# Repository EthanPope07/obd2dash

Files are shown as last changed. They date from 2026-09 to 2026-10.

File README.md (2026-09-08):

# OBD2Dash

An ESP32-S3 CAN-to-BLE bridge for an iPad vehicle dashboard. The firmware discovers each ECU's supported current-data PIDs and forwards complete raw responses through a versioned BLE GATT stream.

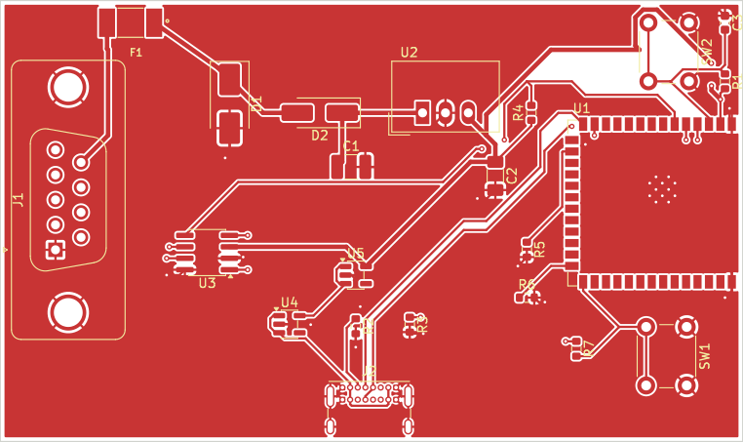
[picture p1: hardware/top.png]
Compact board preview


## Status

The original reader was a breadboard diagnostic sketch. This revision replaces its receive path and adds supported-PID discovery, ISO-TP reassembly and BLE. The new firmware has host regression tests; vehicle and iPad integration testing are still required. Do not represent the new implementation as vehicle-validated yet.

The PCB is a compact prototype, not a fabrication-qualified automotive module. See hardware/Review.md for the supplied review and its unresolved decoupling, component-selection and power-protection findings. That report is preserved as source evidence, not a new electrical signoff.

## Scope of "all PIDs"

- Service 01 (current powertrain data), PID 00 through FF.
- Every advertised support page, not a fixed shortlist of dashboard sensors.
- Separate support maps and responses for eight physical ECU addresses.
- Classical CAN with 11-bit IDs: requests 7E0–7E7, responses 7E8–7EF.
- 500 kbit/s by default; configurable 250 kbit/s.
- Raw response preservation, including multi-frame PIDs. The dashboard applies PID-specific formulas.
- Not manufacturer-specific services, all OBD diagnostic modes, 29-bit CAN, CAN FD, or legacy K-line/J1850.

A vehicle cannot return a PID it does not implement. A discovery timeout is reported as incomplete, not silently interpreted as no support.

## Data flow

CAN request -> ECU response -> ISO-TP reassembly -> timestamped raw PID record -> 20-byte BLE fragments -> iPad reassembly and decoding.

There is one outstanding physical request at a time. All supported data PIDs are polled round-robin; support pages are refreshed between sweeps after at least 60 seconds. Requests have a 50 ms minimum gap, 300 ms inactivity timeout and 5-second absolute deadline. Discovery retries transient failures up to three times. Sample failures produce status records and are retried on later sweeps.

This prioritizes coverage rather than high-rate gauges: polling many PIDs or offline ECUs makes a sweep longer. No fixed update-rate guarantee is claimed.

## Hardware and build

The supplied PCB identifies ESP32-S3-WROOM-1 and TI TCAN337:
- GPIO4 -> TCAN337 TXD
- GPIO5 <- TCAN337 RXD

Confirm the external connector cable pinout and power design before connecting hardware. The firmware sends only Mode 01 requests and ISO-TP flow control; BLE provides no arbitrary CAN-write interface.

Open firmware/obd2dash/obd2dash.ino in Arduino IDE. Select ESP32S3 Dev Module using the Espressif ESP32 package. BLE and TWAI ship with that package. Configure pins and bitrate in Config.h. No WiFi credentials or cloud services are required.

    arduino-cli compile --fqbn esp32:esp32:esp32s3 firmware/obd2dash

## Repository

- firmware/obd2dash: request engine, protocol core and BLE stream
- docs/BLE.md: exact wire format and app integration
- tools/decode_ble.py: reference decoder for notification hex lines
- tests: host protocol and decoder regression tests
- hardware: supplied KiCad source, local footprints, DRC reports and previews

## Tests

    g++ -std=c++17 -Wall -Wextra -Werror tests/protocol_test.cpp -o protocol_test
    ./protocol_test
    python -m unittest discover -s tests -p "test_*.py"

The C++ tests exercise support-map boundaries, independent ECU maps, all 4,088 ISO-TP multi-frame lengths from 8 to 4,095 bytes, sequence rollover/errors, negative responses and maximum-length BLE serialization. Tests do not replace CAN simulator, vehicle or radio testing.

## References

- [Espressif BLE notification example](https://github.com/espressif/arduino-esp32/tree/master/libraries/BLE/examples/Notify)
- [ISO-TP transport overview](https://docs.kernel.org/networking/iso15765-2.html)
- [OBD support-page explanation](https://www.csselectronics.com/pages/obd2-explained-simple-intro)

## Verified build

Compiled successfully with Espressif Arduino-ESP32 3.3.11 (bundled BLE 3.3.11), target esp32:esp32:esp32s3, board defaults.

- Program storage: 576,620 / 1,310,720 bytes (43%).
- Static global RAM: 31,744 / 327,680 bytes (9%).
- Host C++ protocol regression suite: passed.
- Python BLE decoder suite: 4 tests passed.

No device was flashed. These compile figures do not measure peak runtime RAM. Vehicle/CAN simulator tests and iPad integration remain outstanding; follow docs/VALIDATION.md.

## iPad dashboard

The native SwiftUI receiving app is in [ipad](ipad/README.md). Open ipad/OBD2Dash.xcodeproj on a Mac, select your signing team and run on an iPad with iPadOS 17+. It automatically connects while foregrounded and displays RPM, speed and coolant gauges alongside a searchable list of supported/observed PIDs.

Unknown PIDs are shown as raw bytes, not guessed numbers. The app has an explicitly labeled --demo mode for UI previews. See the app README for build and physical-device validation instructions.

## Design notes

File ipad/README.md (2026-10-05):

# OBD2Dash for iPad

A native SwiftUI dashboard for the BLE stream in this repository. Requires iPadOS 17 or newer. No third-party app dependencies.

## Build with GitHub and install from Windows (free Apple account)

1. Open [the iPad app workflow](https://github.com/EthanPope07/obd2dash/actions/workflows/ipad.yml). Builds run automatically when app code changes. To rebuild manually, sign in as a repository collaborator, choose **Run workflow**, and select `main`.
2. Open a successful run. Under **Artifacts**, download **OBD2Dash-iPad-unsigned** (GitHub sign-in required), then extract the downloaded ZIP to get `OBD2Dash-unsigned.ipa`. Artifacts expire after 30 days; run the workflow again if needed.
3. Install [Sideloadly for Windows](https://sideloadly.io/) and its required Apple device components using its current official instructions. Connect your iPad by USB, unlock it, and trust the computer.
4. Select the iPad and drag the `.ipa` into Sideloadly. Use **Apple ID Sideload** with your own free Apple account and start installation. Enter account credentials only in the local signing tool, never in this repository or GitHub Actions.
5. If prompted, trust your developer profile under **Settings > General > VPN & Device Management**. Enable **Settings > Privacy & Security > Developer Mode** and restart if requested.
6. Open OBD2Dash and allow Bluetooth access. Power on the scanner with this repository's firmware; the foreground app connects automatically.

Free-account signing lasts seven days. Refresh or reinstall with Sideloadly using the same account and bundle identifier; see its [FAQ](https://sideloadly.io/faq) for automatic refresh and account limits. No paid developer membership or personally owned Mac is needed for this workflow. The iPad must run iPadOS 17 or newer.

GitHub tests the protocol core, builds the simulator app, and builds an unsigned Release app for physical ARM64 iPads. It checks the device platform and architecture, packages `Payload/OBD2Dash.app` as an IPA, and supplies `SHA256SUMS.txt`. The IPA cannot be installed directly until Sideloadly signs it. No Apple credentials or signing certificates are used by CI. A successful build does not verify physical installation or BLE behavior; those still require an iPad and scanner.

## Run on an iPad with Xcode

1. Clone the repository on a Mac with Xcode 15 or newer (Xcode 16 recommended).
2. Open ipad/OBD2Dash.xcodeproj.
3. In the OBD2Dash target's Signing & Capabilities, select your development team. Change the bundle identifier if your account requires it.
4. Select your attached iPad as the run destination and run the app. Enable Developer Mode on the iPad if requested.
5. Allow Bluetooth access when prompted, then power on the scanner running this repository's firmware.

The app scans for the service UUID, connects, discovers the notify characteristic and subscribes automatically. It remembers the first successfully subscribed scanner. Use the connection menu to reconnect or forget that scanner. It will not silently switch to a different remembered device.

Automatic connection/reconnection is foreground-only. Backgrounding the app stops scanning and disconnects; returning to the foreground reconnects. Bluetooth permission and a powered-on radio are required. It does not pair through the iPad Settings screen.

## Dashboard

- Three large gauges: RPM, speed in km/h, and coolant temperature in Celsius.
- A gauge ECU selector keeps values from different ECUs separate.
- A searchable list includes every PID advertised in support maps or observed in samples, keyed by ECU and PID.
- Common scalar PIDs show numeric values and units. Unknown/encoded PIDs remain visible as raw data; expand any row to inspect the bytes and device timestamp.
- Support-map rows start as awaiting a first sample. Timeouts and ECU errors never become zero-valued readings.
- Gauges blank when disconnected or when the latest successful sample is over 15 seconds old. Old list values remain marked stale.
- The app may wait until the next support sweep to learn all supported PIDs. It never invents unsupported rows.

The firmware polls broadly, so vehicles with many PIDs may not refresh gauges quickly. A priority polling mode can be added to the firmware later; it is not implied by this UI.

## Preview without a scanner

Open the top-right three-dot menu and choose **Demo: 2017 Infiniti QX70**. No scanner or Bluetooth permission is needed to run the simulation. The gauges and 19 PID rows update once per second through a repeating stop-and-go drive, with acceleration, cruise, braking, idle and gradual engine warm-up.

An orange demo banner and connection status identify all readings as simulated. This is an illustrative vehicle profile, not measured QX70 data or a claim that your car supports every demonstrated PID. Values pass through the same PID decoder used for live readings.

Demo pauses Bluetooth scanning and disconnects any scanner without forgetting it. **Exit demo mode** clears simulated records and resumes normal Bluetooth connection behavior. Simulation pauses in the background. Xcode's `--demo` launch argument still works for previews.

## Protocol and testing

The app shares a Foundation-only parser/model source with the OBDCore Swift package. It matches docs/BLE.md, checks packet bounds and identity, discards gaps and incomplete records, and expires partial reassembly after 15 seconds. Device milliseconds are uptime, not calendar time.

Run on macOS:

    swift test --package-path ipad/OBDCore
    xcodebuild -project ipad/OBD2Dash.xcodeproj -scheme OBD2Dash -sdk iphonesimulator -destination 'generic/platform=iOS Simulator' CODE_SIGNING_ALLOWED=NO build

The GitHub workflow runs these checks on macOS. The development host used to add this app was Windows, so native iPad UI rendering and physical CoreBluetooth behavior must still be verified on an iPad.

Numeric decoding is intentionally limited to implemented scalar definitions with exact expected byte counts. Other PIDs preserve their complete raw readings. Decoder reference: https://www.csselectronics.com/pages/obd2-pid-table-on-board-diagnostics-j1979

## Files

- OBD2Dash/DashboardModel.swift: foreground connection lifecycle and notification handling
- OBD2Dash/DashboardView.swift: gauges and searchable PID list
- OBDCore/Sources/OBDCore/Telemetry.swift: reassembly, support maps, scalar decoding and freshness
- OBDCore/Tests: regression tests

No firmware modifications are needed. No vehicle-write control is exposed by the app.

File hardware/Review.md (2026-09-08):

# obd2Dash compact prototype revision

The board outline has been reduced from **95 × 54.5 mm to 82.5 × 49 mm**, a **21.9% reduction in PCB area** (5,177.5 to 4,042.5 mm²). This is the PCB outline, not the assembled envelope: the USB connector and ESP32 antenna extend beyond it.

Open `obd2Dash.kicad_pro` in KiCad 10 with the other files in this folder. The original OneDrive project was not modified. The schematic, component values, net assignments, and two-layer construction are preserved.

## What changed

- Moved the DE-9 connector J1 10 mm inward and moved fuse F1 5 mm upward; reduced unused space at the left and top edges.
- Rerouted the J1 power feed and CANH/CANL connections to accommodate the connector move.
- Replaced the long IO4/IO5 routes around the lower and right edges with shorter routes on the back layer. This removes the copper-at-the-board-edge defects.
- Connected the previously isolated C3 ground, R7 3.3 V supply, and J2 CC2 connection to R3.
- Adjusted the ESP32 enable trace near SW2 to restore clearance.
- Added a front ground pour, retained the back ground pour, and refilled both. The ESP32 footprint's antenna keepout remains present, prohibiting tracks, vias, and zone fill.
- Corrected USB ground thermal connections and SW2 ground thermal clearance.
- Increased the twelve 0.20 mm ESP32 ground-pad holes to 0.30 mm to meet the existing minimum-hole rule. This is a deliberate footprint customization; the associated copper pads are retained and pass annular-width checks.
- Corrected the undersized fuse reference text and moved board-edge-crossing connector/module graphics to the fabrication layer. Repositioned J1's reference inside the outline.

## Verification

Checked with KiCad CLI **10.0.4**, with copper zones refilled and schematic parity enabled.

| Check | Original | Revised |
|---|---:|---:|
| DRC errors, excluding separately reported missing connections | 51 | 0 |
| Missing connections | 3 | 0 |
| Schematic parity issues | 0 | 0 |
| DRC warnings | 28 | 1 |

The original 79 DRC violations comprised 29 clearance, 8 copper-edge clearance, 12 hole-size, 2 incomplete thermal relief, 2 dangling-via, 3 silkscreen-edge, 1 text-height, and 22 unavailable-library findings. The three missing connections were reported separately.

The remaining warning is **U1 footprint does not match the RF_Module library copy**. It is visible in `drc-final.json` and has not been excluded. Local footprint libraries are bundled as project snapshots to make the supplied project portable; they are not independent manufacturer verification of the footprints. Review the customized ESP32 footprint before updating it from any library, since a library update could overwrite its drill and graphics changes.

The project retains its existing rule severities and exclusions. It adds one narrowly scoped rule in `obd2Dash.kicad_dru`: **0.15 mm clearance between pads of J2 only**, matching the supplied USB4085 footprint's pad spacing. Other default net clearance remains 0.20 mm; minimum copper-to-board-edge clearance remains 0.50 mm. Confirm that the chosen fabricator supports 0.15 mm spacing. This rule acknowledges the connector geometry; it is not a rerouting repair or a blanket relaxation of clearances. See [GCT's USB4085 documentation](https://gct.co/connector/usb4085) when checking the exact connector variant and land pattern.

The original USB D+/D− routes were retained. Their total segment lengths are approximately 45.78 mm and 45.65 mm, respectively; these totals include connector branches and are not a full differential-path or signal-integrity measurement. No controlled-impedance stackup was supplied, so USB impedance has not been validated. DRC does not verify signal integrity, EMC, thermal performance, or power-supply stability.

Native top and bottom copper plots were exported and visually reviewed. The PNG shows the top copper and silkscreen; the SVG files preserve more detail. The bottom plot is viewed through the board from above, not mirrored for assembly.

## Electrical issues still present in the source design

These were identified during the layout review and are not solved by reconnecting the existing nets:

1. **AP2112 USB regulator U4 has no local input or output capacitor in the supplied schematic.** C1 is on the vehicle-side converter input; C2 is on the combined 3.3 V rail after U5; C3 is on ESP32 EN. Add suitable local capacitors at U4 VIN and VOUT as part of a schematic revision. The manufacturer's typical application uses 1 µF input and output capacitors. [AP2112 datasheet](https://www.diodes.com/datasheet/download/AP2112.pdf).
2. **TCAN337 U3 has no dedicated local supply bypass capacitor.** Its shared bulk capacitor C2 is some distance away. Add a local 100 nF ceramic bypass at U3 VCC/GND and review bulk decoupling. [TI TCAN337 datasheet](https://www.ti.com/lit/ds/symlink/tcan337.pdf).
3. **The vehicle-input protection parts are not fully specified.** D1 is labeled only `D_Zener`, D2 only `D_Schottky`, and F1's 0.75 A value differs from the current footprint's `1812L200_12DR` name. Verify actual part numbers, ratings, and land patterns before ordering. This review does not establish automotive transient immunity or validate simultaneous vehicle/USB power operation.

The antenna overhang and keepout were preserved, consistent with Espressif's preference for placing the module antenna outside the base board. The assembled enclosure and nearby metal still need consideration. [Espressif PCB layout guidance](https://docs.espressif.com/projects/esp-hardware-design-guidelines/en/latest/esp32s3/pcb-layout-design.html).

## Further size reduction

This revision keeps the current parts and most of the established placement. Additional reduction would require a broader rearrangement of the regulator, USB circuit, and switches. The through-hole DE-9 connector, two large pushbuttons, and ESP32 module are the major physical constraints. A smaller connector or smaller switches would permit a more substantial reduction but would change the parts list. The present revision is a compact, connected prototype layout for review, not a fabrication-qualified electrical design.

## Included files

- Native board, unchanged schematic, project settings, and connector-specific design rule.
- Project-local footprint libraries and `fp-lib-table`.
- Original and final machine-readable DRC reports.
- `top.svg`, `bottom.svg`, and `top.png` previews.

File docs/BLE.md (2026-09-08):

# BLE protocol v1

Advertised name: OBD2Dash. Discover by service UUID, not name alone.

| Attribute | UUID | Properties |
|---|---|---|
| Service | 973a0001-6f8a-4db7-a735-79d348be7341 | Primary |
| Stream | 973a0002-6f8a-4db7-a735-79d348be7341 | Notify |
| Info | 973a0003-6f8a-4db7-a735-79d348be7341 | Read |

Subscribe to Stream using CoreBluetooth setNotifyValue(true, for:). The firmware does not require a larger MTU: every notification is 20 bytes, fitting the default 23-byte ATT MTU. The only writable attribute is the notification subscription descriptor. There is no CAN-command characteristic.

## Packet

All multi-byte fields are unsigned little-endian. Serialization is explicit; no compiler-dependent packed C struct is transmitted.

| Offset | Bytes | Meaning |
|---|---:|---|
| 0 | 1 | Version in high nibble (1); kind in low nibble |
| 1 | 1 | Requested PID, or support-page base |
| 2 | 2 | ECU response CAN ID (7E8–7EF) |
| 4 | 2 | Sample sequence, wraps at 65536 |
| 6 | 2 | Offset into the logical payload |
| 8 | 2 | Total logical payload length |
| 10 | 1 | Status |
| 11 | 1 | Fragment payload bytes (1–8) |
| 12 | 8 | Fragment bytes; unused trailing bytes zero-filled |

Kinds: 1 = PID sample, 2 = discovery support-page result.
Statuses: 0 = valid; 1 = timeout; 2 = negative ECU reply; 3 = malformed response; 4 = transport failure; 5 = bus unavailable/recovering.

The logical payload begins with milliseconds since boot (uint32 LE), then:
- Valid PID: raw data bytes after the 41/PID response prefix.
- Valid support page: four bitmap bytes in original ECU order (big-endian bit map).
- Negative response: one NRC byte.
- Other failures: no additional bytes. Never reuse previous sensor bytes as a new successful reading.

For bitmap base B, the most significant bit represents B+1; the least significant bit represents B+32. Continuation PIDs 20,40,...,E0 are support pages, not gauge values.

Example: sequence 0, ECU 7E8, PID 0C, timestamp 0, raw 1A F8:
    11 0c e8 07 00 00 00 00 06 00 00 06 00 00 00 00 1a f8 00 00
RPM is (0x1AF8)/4 = 1726 RPM. Other PIDs can contain multiple values and flags; retain their raw bytes.

## Reassembly

Start at offset zero. Require the same version/kind, ECU, PID, sequence, total length and status for all fragments, and exactly contiguous offsets. Emit a sample only when all total bytes are received. Reject out-of-range lengths, gaps, duplicate or reordered fragments. Clear partial state on disconnect and expire incomplete records. Sequence numbers and timestamps reset on reboot and wrap; they are not wall-clock time.

Notifications are best effort. The 15 ms fragment pacing reduces congestion but does not acknowledge delivery. Use timestamps to mark readings stale. A sequence gap can also reflect samples produced before subscription. Discovery repeats periodically, so a client subscribing late may wait until the next support sweep for all bitmap pages.

A Python reference reassembler is in tools/decode_ble.py; feed one notification hex string per line. The new native iPad client in ipad/ implements this format. It is a new receiving app, not a claim of compatibility with any earlier unpublished app.

## Access

This prototype does not enable pairing or encryption. Nearby clients can subscribe to telemetry. Do not transmit identity/location data through this interface without designing appropriate access control.

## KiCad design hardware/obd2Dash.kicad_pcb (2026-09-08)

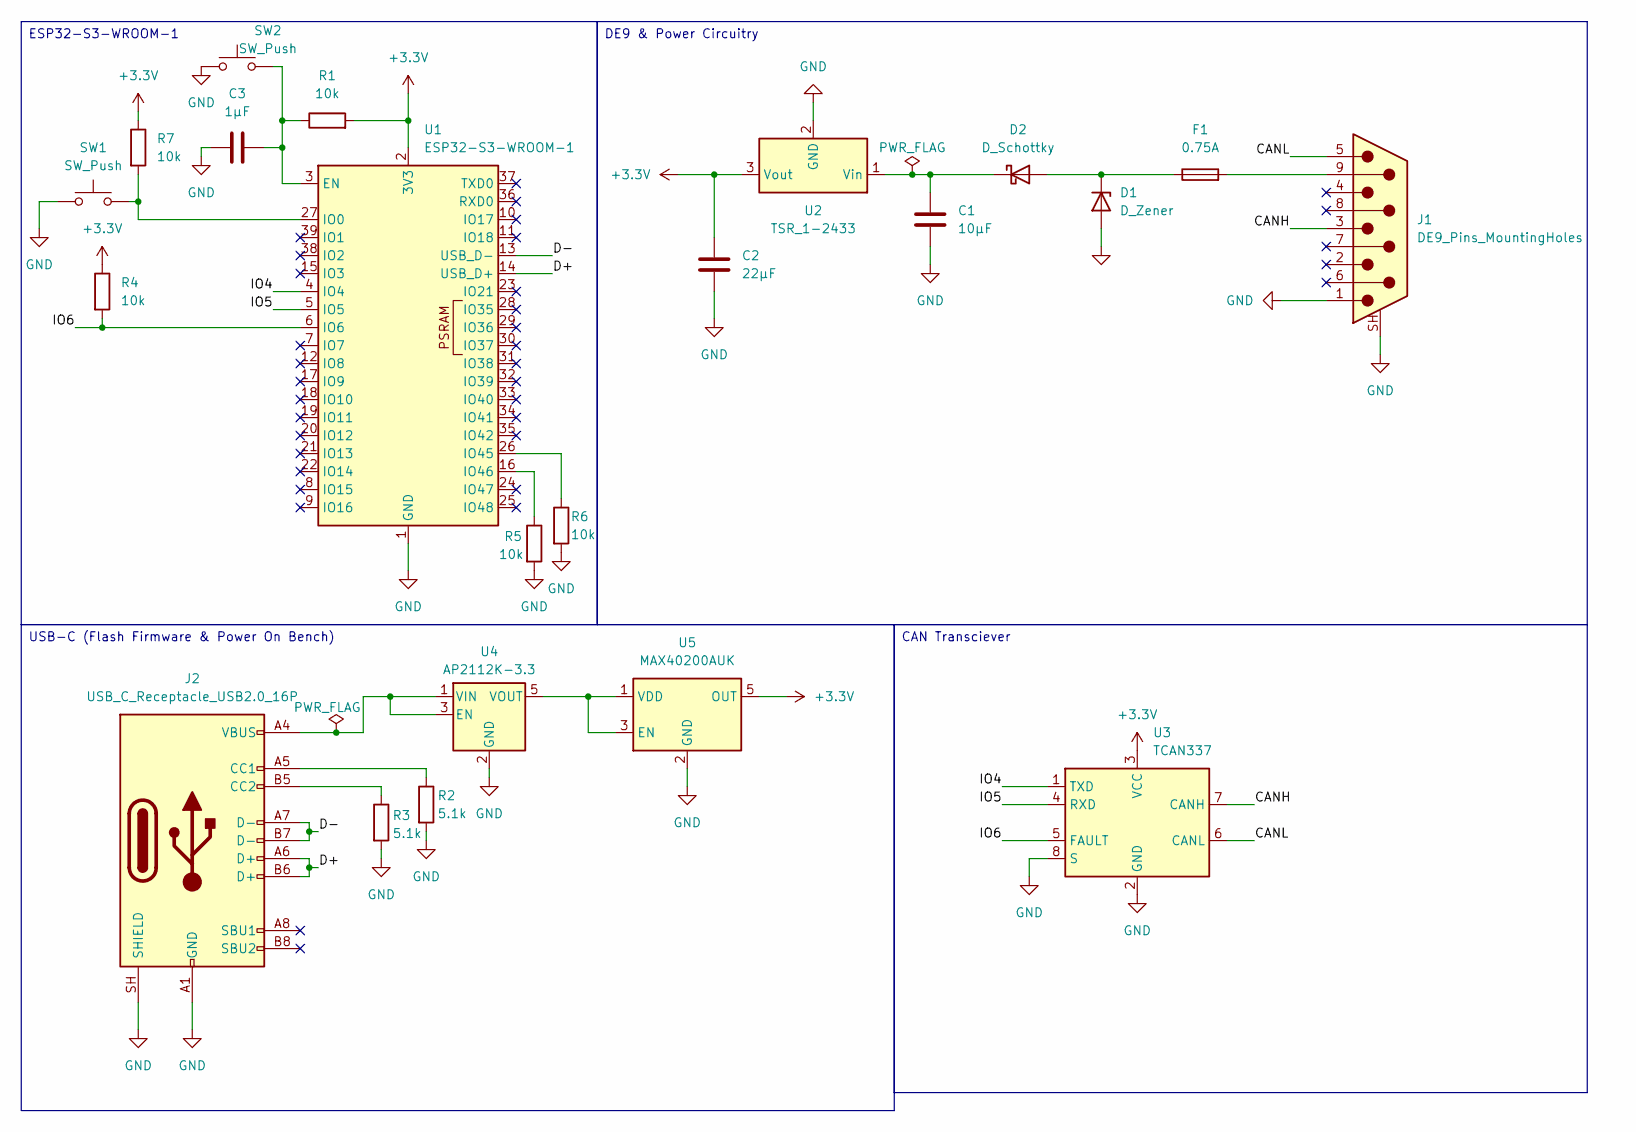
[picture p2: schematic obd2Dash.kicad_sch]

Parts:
C1: 10µF; C_1210_3225Metric_Pad1.33x2.70mm_HandSolder
C2: 22µF; C_1206_3216Metric_Pad1.33x1.80mm_HandSolder
C3: 1µF; C_0603_1608Metric
D1: D_Zener; D_SMB_Handsoldering
D2: D_Schottky; D_SMA_Handsoldering
F1: 0.75A; FUSE_1812L200_12DR
J1: DE9_Pins_MountingHoles; DSUB-9_Pins_Vertical_P2.77x2.84mm_MountingHoles
J2: USB_C_Receptacle_USB2.0_16P; USB_C_Receptacle_GCT_USB4085
R1, R4, R5, R6, R7: 10k; R_0603_1608Metric
R2, R3: 5.1k; R_0603_1608Metric
SW1, SW2: SW_Push; SW_PUSH_6mm_H4.3mm
U1: ESP32-S3-WROOM-1
U2: TSR_1-2433; Converter_DCDC_TRACO_TSR-1_THT
U3: TCAN337; SOIC-8_3.9x4.9mm_P1.27mm
U4: AP2112K-3.3; SOT-23-5
U5: MAX40200AUK; SOT-23-5

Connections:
+3.3V: C2.1, R1.2, R4.1, R7.1, U1.2 (3V3), U2.3 (Vout), U3.3 (VCC), U5.5 (OUT)
/CANH: J1.3, U3.7 (CANH)
/CANL: J1.5, U3.6 (CANL)
/D+: J2.A6 (D+), J2.B6 (D+), U1.14 (USB_D+)
/D-: J2.A7 (D-), J2.B7 (D-), U1.13 (USB_D-)
/IO4: U1.4 (IO4), U3.1 (TXD)
/IO5: U1.5 (IO5), U3.4 (RXD)
/IO6: R4.2, U1.6 (IO6), U3.5 (FAULT)
GND: C1.2, C2.2, C3.1, D1.2 (A), J1.1, J1.SH (PAD), J2.A1 (GND), J2.A12 (GND), J2.B1 (GND), J2.B12 (GND), J2.SH (SHIELD), R2.2, R3.2, R5.2, R6.2, SW1.1, SW2.1, U1.1 (GND), U1.40 (GND), U1.41 (GND), U2.2 (GND), U3.2 (GND), U3.8 (S), U4.2 (GND), U5.2 (GND)
unnamed: D1.1 (K), D2.2 (A), F1.1
unnamed: C1.1, D2.1 (K), U2.1 (Vin)
unnamed: F1.2, J1.9
unnamed: J2.A5 (CC1), R2.1
unnamed: J2.B5 (CC2), R3.1
unnamed: C3.2, R1.1, SW2.2, U1.3 (EN)
unnamed: R7.2, SW1.2, U1.27 (IO0)
unnamed: R6.1, U1.26 (IO45)
unnamed: R5.1, U1.16 (IO46)
unnamed: J2.A4 (VBUS), J2.A9 (VBUS), J2.B4 (VBUS), J2.B9 (VBUS), U4.1 (VIN), U4.3 (EN)
unnamed: U4.5 (VOUT), U5.1 (VDD), U5.3 (EN)

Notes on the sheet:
ESP32-S3-WROOM-1
CAN Transciever
DE9 & Power Circuitry
USB-C (Flash Firmware & Power On Bench)

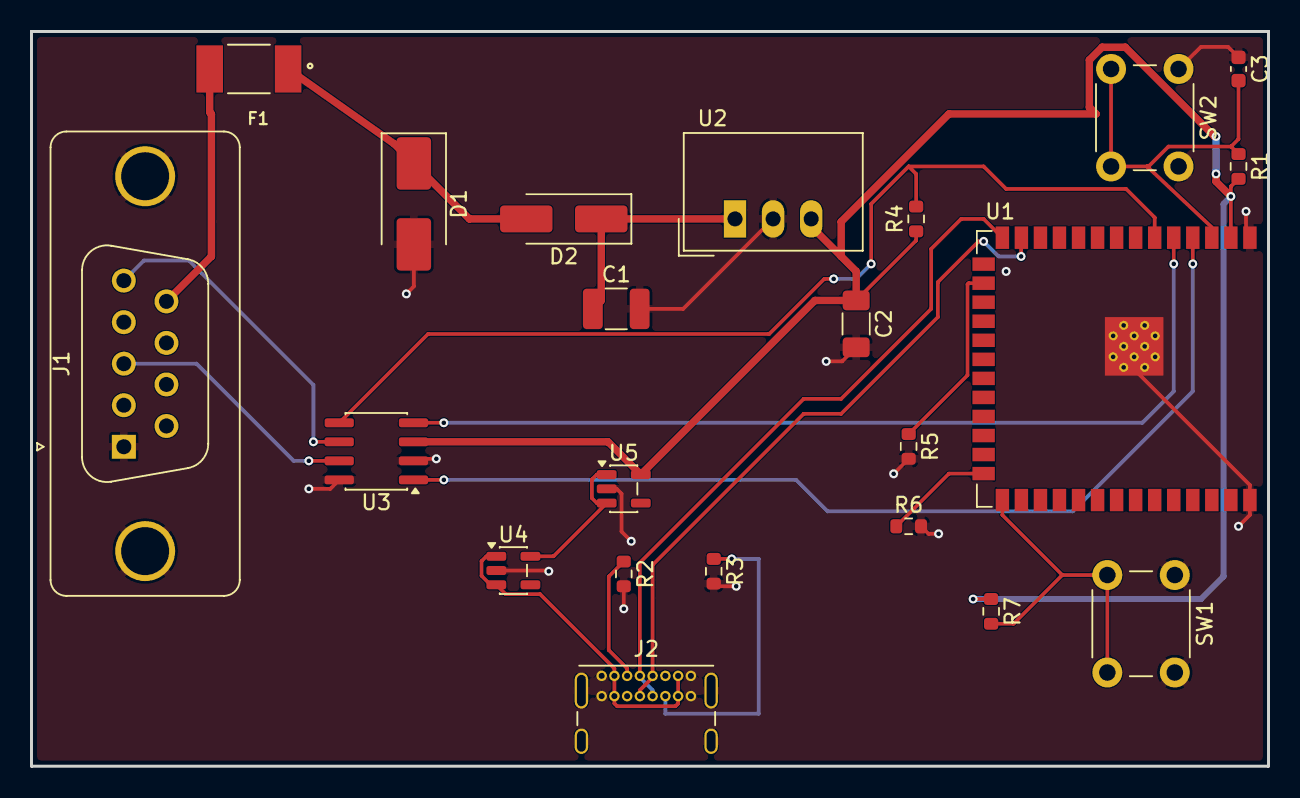
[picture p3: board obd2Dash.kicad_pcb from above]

Board: 2 copper layers, 82.5 x 49.0 mm, 22 parts (0 on the bottom side), 20 nets.

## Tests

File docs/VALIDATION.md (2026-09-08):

# Integration validation

The host tests cover parsing and serialization. They do not exercise TWAI hardware, BLE delivery, ECU timing or the iPad UI.

Before calling this revision deployed:

1. Compile for the installed ESP32-S3 target. Confirm module flash settings match the actual module.
2. On a CAN simulator or stationary vehicle with the appropriate wiring, observe requests 7E0–7E7 and match replies 7E8–7EF. Verify bitrate first.
3. Compare each reported support map with a trusted scan tool. Include a vehicle or simulator advertising a continuation page above 20.
4. Test two ECUs supporting different PID sets. Confirm the dashboard does not combine their values under one key.
5. Simulate multi-frame replies, wrong consecutive-frame sequence, missing frames, negative replies and response-pending. A failure must never become a successful stale value.
6. Subscribe using a BLE inspector at the default MTU. Decode complete notification records using tools/decode_ble.py.
7. Disconnect during a fragmented record, reconnect and resubscribe. Discard the incomplete record. Wait for the next support-page sweep if needed.
8. Unplug the CAN source and restore it. Verify timeouts/recovery, rediscovery and continued BLE service.
9. Measure a full sweep with the actual supported-PID count. Coverage-oriented polling is not a guaranteed high-rate dashboard schedule.
10. Review the PCB's existing electrical findings separately before fabrication or vehicle-powered testing.

Example conversions after successful reassembly:
- 0C, two bytes A/B: RPM = (256*A+B)/4.
- 0D, one byte A: speed = A km/h.
- 05, one byte A: coolant = A-40 degrees C.

Validate byte count before applying a formula. Do not apply these scalar formulas to other PIDs or treat status failures as zero.

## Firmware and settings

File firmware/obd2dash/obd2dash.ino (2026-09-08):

#include <Arduino.h>
#include <atomic>
#include "driver/twai.h"
#include <BLEDevice.h>
#include <BLEServer.h>
#include <BLEUtils.h>
#include <BLE2902.h>
#include "Config.h"
#include "Protocol.h"

struct Ecu {
  obd::Pids pids;
  bool present=false;
  bool complete=false;
};
Ecu ecus[8];
obd::Receiver receiver;
BLECharacteristic* stream=nullptr;
BLE2902* subscription=nullptr;
std::atomic<bool> connected{false}, restartAdvertising{false};
std::atomic<uint32_t> connectionEpoch{0};
uint16_t sampleSequence=0;
uint32_t lastRequest=0,lastDiscovery=0;
unsigned ecuCursor=0,pidCursor=1;
bool discovered=false;
uint32_t goodSamples=0,failedSamples=0;

class Connections : public BLEServerCallbacks {
  void onConnect(BLEServer*) override {
    connectionEpoch.fetch_add(1);
    connected.store(true);
  }
  void onDisconnect(BLEServer*) override {
    connected.store(false);
    connectionEpoch.fetch_add(1);
    restartAdvertising.store(true);
  }
};

void serviceBle() {
  if(restartAdvertising.exchange(false)) {
    subscription->setNotifications(false);
    BLEDevice::startAdvertising();
  }
}
void publish(uint8_t kind,uint16_t ecu,uint8_t pid,obd::Result status,
             const uint8_t* data,uint16_t length) {
  const uint16_t seq=sampleSequence++;
  const uint32_t stamp=millis(), epoch=connectionEpoch.load();
  if(!connected.load() || !subscription->getNotifications()) return;
  uint8_t frame[20];
  for(uint16_t offset=0;offset<length+4;offset+=8) {
    if(!connected.load() || connectionEpoch.load()!=epoch ||
       !subscription->getNotifications()) return;
    if(!obd::packet(frame,kind,seq,ecu,pid,status,stamp,data,length,offset)) return;
    stream->setValue(frame,sizeof(frame));
    stream->notify();
    // Notifications are best effort, not an acknowledged sample transport.
    delay(BLE_FRAGMENT_GAP_MS);
  }
}

bool busReady() {
  twai_status_info_t info{};
  if(twai_get_status_info(&info)!=ESP_OK) return false;
  if(info.state==TWAI_STATE_BUS_OFF) {
    Serial.println("CAN bus-off: initiating recovery");
    twai_initiate_recovery();
    return false;
  }
  if(info.state==TWAI_STATE_STOPPED) return twai_start()==ESP_OK;
  return info.state==TWAI_STATE_RUNNING;
}

bool sendCan(uint16_t id,const uint8_t* data) {
  twai_message_t frame{};
  frame.identifier=id;
  frame.data_length_code=8;
  frame.ss=1; // Do not endlessly retry requests on an absent/failed bus.
  memcpy(frame.data,data,8);
  return twai_transmit(&frame,pdMS_TO_TICKS(50))==ESP_OK;
}

obd::Result request(uint8_t ecu,uint8_t pid) {
  serviceBle();
  receiver.reset(pid);
  if(!busReady()) { delay(100); return obd::Result::BusOff; }
  while(uint32_t(millis()-lastRequest)<REQUEST_GAP_MS) delay(1);
  // Discard old queued frames before starting a new physical transaction.
  twai_message_t stale{};
  for(unsigned i=0;i<128 && twai_receive(&stale,0)==ESP_OK;++i) {}
  uint32_t alerts=0;
  twai_read_alerts(&alerts,0);
  const uint8_t payload[8]={2,1,pid,0,0,0,0,0};
  lastRequest=millis();
  if(!sendCan(0x7e0+ecu,payload)) return obd::Result::Transport;
  uint32_t start=millis(), activity=start, waitBudget=RESPONSE_MS;
  // Absolute cap also bounds repeated response-pending replies.
  while(uint32_t(millis()-start)<TRANSACTION_MAX_MS &&
        uint32_t(millis()-activity)<waitBudget) {
    twai_read_alerts(&alerts,0);
    if(alerts & TWAI_ALERT_BUS_OFF) return obd::Result::BusOff;
    if(alerts & (TWAI_ALERT_RX_QUEUE_FULL|TWAI_ALERT_TX_FAILED))
      return obd::Result::Transport;
    twai_message_t frame{};
    if(twai_receive(&frame,pdMS_TO_TICKS(10))!=ESP_OK) continue;
    if(frame.extd || frame.rtr || frame.identifier!=unsigned(0x7e8+ecu)) continue;
    const auto step=receiver.feed(frame.data,frame.data_length_code);
    if(step==obd::Step::Ignore) continue;
    activity=millis(); waitBudget=RESPONSE_MS;
    if(step==obd::Step::Error) return obd::Result::Malformed;
    if(step==obd::Step::FlowControl) {
      const uint8_t fc[8]={0x30,0,5,0,0,0,0,0}; // CTS, unlimited block, 5 ms STmin.
      if(!sendCan(0x7e0+ecu,fc)) return obd::Result::Transport;
    } else if(step==obd::Step::Pending) {
      receiver.reset(pid);
      waitBudget=TRANSACTION_MAX_MS;
    } else if(step==obd::Step::Done) {
      return receiver.negative ? obd::Result::Negative : obd::Result::Ok;
    }
  }
  return obd::Result::Timeout;
}

void discovery() {
  Serial.println("Discovering each ECU's Mode 01 support pages");
  for(unsigned e=0;e<8;++e) {
    ecus[e]=Ecu{};
    for(unsigned base=0;base<=0xe0;base+=0x20) {
      obd::Result result=obd::Result::Timeout;
      for(unsigned attempt=0;attempt<3;++attempt) {
        result=request(e,uint8_t(base));
        if(result==obd::Result::Ok || result==obd::Result::Negative) break;
      }
      if(result!=obd::Result::Ok) {
        // A failed page is not interpreted as an empty supported-PID map.
        const uint8_t nrc=receiver.negative;
        publish(2,0x7e8+e,uint8_t(base),result,&nrc,
                result==obd::Result::Negative ? 1 : 0);
        break;
      }
      if(receiver.length!=6 ||
         !ecus[e].pids.addPage(uint8_t(base),receiver.bytes+2,receiver.length-2)) {
        publish(2,0x7e8+e,uint8_t(base),obd::Result::Malformed,nullptr,0);
        break;
      }
      ecus[e].present=true;
      publish(2,0x7e8+e,uint8_t(base),obd::Result::Ok,receiver.bytes+2,4);
      if(base==0xe0 || !ecus[e].pids.has(uint8_t(base+32))) {
        ecus[e].complete=true; break;
      }
    }
    unsigned count=0;
    for(unsigned p=1;p<256;++p)
      if(p%32 && ecus[e].pids.has(uint8_t(p))) ++count;
    Serial.printf("ECU %03X: %u data PIDs; discovery %s\n",0x7e8+e,count,
                  ecus[e].complete ? "complete" : "unavailable/incomplete");
  }
  lastDiscovery=millis(); discovered=true; ecuCursor=0; pidCursor=1;
}

void setup() {
  Serial.begin(115200);
  BLEDevice::init("OBD2Dash");
  auto* server=BLEDevice::createServer();
  server->setCallbacks(new Connections());
  auto* service=server->createService(SERVICE_UUID);
  stream=service->createCharacteristic(STREAM_UUID,BLECharacteristic::PROPERTY_NOTIFY);
  subscription=new BLE2902();
  stream->addDescriptor(subscription);
  auto* info=service->createCharacteristic(INFO_UUID,BLECharacteristic::PROPERTY_READ);
  info->setValue("OBD2Dash v1; Mode01; CAN11; raw; 20-byte fragments");
  service->start();
  auto* advertising=BLEDevice::getAdvertising();
  advertising->addServiceUUID(SERVICE_UUID);
  advertising->setScanResponse(true);
  BLEDevice::startAdvertising();

  twai_general_config_t general=TWAI_GENERAL_CONFIG_DEFAULT(CAN_TX_PIN,CAN_RX_PIN,TWAI_MODE_NORMAL);
  general.rx_queue_len=128;
  general.tx_queue_len=0;
  general.alerts_enabled=TWAI_ALERT_BUS_OFF|TWAI_ALERT_RX_QUEUE_FULL|TWAI_ALERT_TX_FAILED;
  static_assert(CAN_BITRATE==500000 || CAN_BITRATE==250000,"Unsupported CAN bitrate");
  twai_timing_config_t timing=TWAI_TIMING_CONFIG_500KBITS();
  const twai_timing_config_t slow=TWAI_TIMING_CONFIG_250KBITS();
  if(CAN_BITRATE==250000) timing=slow;
  twai_filter_config_t filter=TWAI_FILTER_CONFIG_ACCEPT_ALL();
  if(twai_driver_install(&general,&timing,&filter)!=ESP_OK || twai_start()!=ESP_OK) {
    Serial.println("CAN initialization failed; check pins/configuration");
    while(true) delay(1000);
  }
}

void loop() {
  serviceBle();
  // Rediscover only between full sweeps so slow ECUs cannot starve later PIDs.
  if(!discovered || (ecuCursor>=8 && uint32_t(millis()-lastDiscovery)>=REDISCOVER_MS)) {
    discovery();
  }
  if(ecuCursor>=8) {
    ecuCursor=0; pidCursor=1;
    Serial.printf("Samples: %lu valid, %lu failed\n",
                  (unsigned long)goodSamples,(unsigned long)failedSamples);
    delay(50);
  }
  while(ecuCursor<8) {
    while(pidCursor<256) {
      const uint8_t pid=uint8_t(pidCursor++);
      if(pid%32==0 || !ecus[ecuCursor].pids.has(pid)) continue;
      auto result=request(ecuCursor,pid);
      if(result==obd::Result::Ok) {
        ++goodSamples;
        publish(1,0x7e8+ecuCursor,pid,result,receiver.bytes+2,receiver.length-2);
      } else {
        ++failedSamples;
        uint8_t nrc=receiver.negative;
        publish(1,0x7e8+ecuCursor,pid,result,&nrc,result==obd::Result::Negative ? 1 : 0);
      }
      return;
    }
    ++ecuCursor; pidCursor=1;
  }
  delay(10);
}

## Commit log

2026-09-08 Implement supported Mode 01 polling and versioned BLE telemetry
    [obd2Dash.kicad_pcb, obd2Dash.kicad_sch]
2026-09-09 Fix device architecture verification before IPA packaging
